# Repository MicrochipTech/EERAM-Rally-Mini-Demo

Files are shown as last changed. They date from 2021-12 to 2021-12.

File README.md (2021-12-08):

# EERAM Rally Mini Demo

https://user-images.githubusercontent.com/7294232/145284501-e43a5de2-cd9b-4e7f-be3a-1c69db363a6e.mp4

[Full Video](https://vimeo.com/604094518)

## ABOUT
The demo is supposed to showcase the special capabilities of this part in a game that simulates a “Black Box” recorder function. So that the race outcome can be examined after the fact any number of times. From the beginning of the race, every move by the driver, and the positions of the other cars is recorded 30 times a second into the EERAM which can hold 30 seconds of race time. If it becomes full, the program wraps back to the beginning to form a circular buffer, always marking the last sample taken.

The demo uses an SPI EERAM part, with a density of 64kbits, the  [**48L640**](https://www.microchip.com/wwwproducts/en/48L640). The EERAM is mounted onto a removable PIM board. By removing the board, it gives the customer the clear message that this memory can be disturbed or removed from power at any time, and still retain the data written to it up to that point. The EERAM family includes lower and higher density parts (upwards to 1Mbit), on I2C and SPI serial buses. Only the 64K SPI PIM and 1M Click boards are supported by this demo. By being removable, the PIM board allows for immediate communications and power disturbance, so that the data-saving features of the EERAM can be clearly demonstrated.

EERAM is a standalone SRAM memory with shadow EEPROM backup that retains the contents of the SRAM memory when system power is lost. The EERAM uses a small external capacitor (VCAP on the PIM
board) to provide the energy needed to store the contents of the SRAM onto the EEPROM whenever power is lost. Unlike NVSRAM, no external battery is needed. EERAM offers unlimited erase and write cycles to the SRAM memory and FRAM-like functionality at a fraction of the price.

## Mini Rally Game Board
The board showcases some other Microchip components. This includes the PIC18F47K40 8-bit MCU, and the MCP16252 DC/DC Boost converter. Power is supplied by two AAA batteries which are reverse
polarity protected. Power is controlled by a small slide switch on the back near the batteries. The boost converter ensures that every ounce of juice from the batteries will be available to the game.

Besides the supplied EERAM PIM board socket on the side, there is also a MikroBUS™ (Click board) interface to the back, where the 1Mbit EERAM Click demo board (in production soon) can be plugged in and used instead of the PIM. Future software versions may also support I2C PIM boards, and be able to use the larger memory array, but at this point, using the Click board can only record 64K of data, same as the PIM. The demo will only be supplied with the PIM.

The display used is a 128 x 160 pixel TFT display with LED backlight. The game operation is smooth and clear, taking advantage of the processing power of this 8-bit MCU and of the display resolution and color capabilities. Dimming is controlled by an MCU PWM channel.

Sound is produced by a rear-facing Piezo speaker. We have tried to avoid annoying continuous sounds, but some basic sounds have been added to enhance the demo board experience, such as a sound when the racer hits another car, when the PIM is unplugged or plugged in, and when the race review (instant-replay) mode is selected. Presently, there is no option to disable sound.

## Using the Demo
Power is controlled by a slide switch near the batteries (circled below). Always turn the switch to “0” when not in use to save battery life.

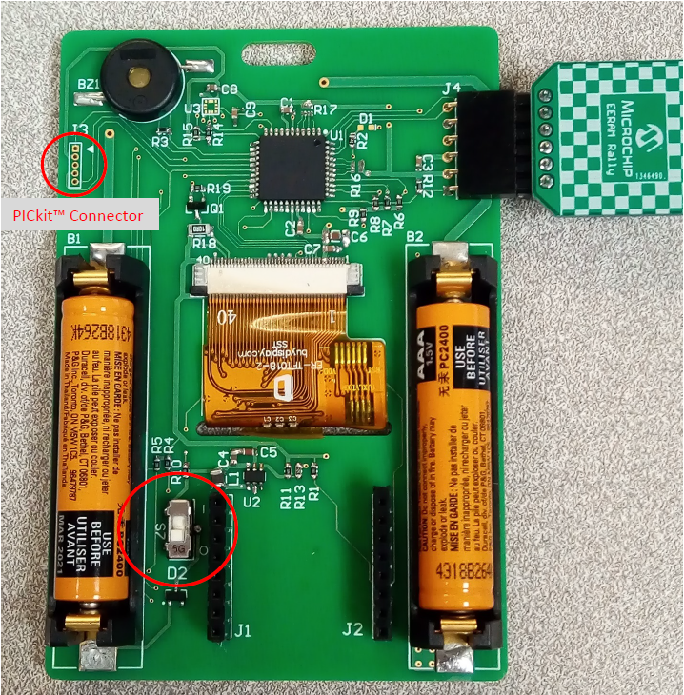
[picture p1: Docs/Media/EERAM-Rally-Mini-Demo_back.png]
Demonstration


On Power ON, the screen will splash the Microchip name and logo then instruct the user to hit either the “A” button, to begin a new race, or the “B” button, to review the last race. The EERAM PIM must be plugged in correctly for either of these modes to operate.

The directional buttons are used to steer the red car around the competitor cars. The user can move forward and back, but most of the time just left and right buttons are the best to use.

Just like the red wedge demo, users can continue racing until a crash (the object is not to win but rather to avoid a crash), or until power is turned off or the memory card is unplugged. Afterwards, the user can either begin a new race or review the previous one. After reviewing it once, it pauses and repeats forever, or until a new race is selected. The competitor car pattern is hard coded, so every race offers the same challenge. If you don’t crash while racing, the track pattern will repeat itself after about a minute, but there are some tight spots which are hard to complete without practice.

Demonstration

## **Support**
To submit a support ticket request, please contact [Microchip Support](https://microchipsupport.force.com/s/)

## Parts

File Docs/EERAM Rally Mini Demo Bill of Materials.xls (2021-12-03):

Quantity | Designator | Description_ | Manufacturer 1 | Manufacturer Part Number 1 | Supplier 1 | Supplier Part Number 1 | Supplier 100pc Unit Price | Extended
2 | B1, B2 | BATT HOLDER 1CELL SMD AAA | Keystone Electronics | 1020 | Digi-Key | 36-1020-ND | 1.91 | 3.82
1 | BZ1 | MECH HW Buzzer Single Tone 4kHz Piezo 30V SMD | TDK Corporation | PS1240P02CT3 | Digi-Key | 445-5229-1-ND | 0.5256 | 0.5256
6 | C1, C2, C3, C7, C8, C9 | CAP CER 0.1uF 50V 20% X7R SMD 0603 | TDK, KEMET, Panasonic | C1608X7R1H104M, | local stock |  |  | 0
1 | C4 | CAP CER 4.7uF 10V 10% X5R SMD 0603, | TDK, KEMET, Panasonic | C0603C475K8PACTU | local stock | 445-5098-1-ND, 399-5503-1-ND, PCC2479CT-ND |  | 0
1 | C5 | CAP CER 10uF 10V 20% X5R SMD 0603 | TDK, KEMET, Panasonic | ECJ-1VB1A106M | local stock |  |  | 0
1 | C6 | CAP CER 10uF 16V 10% X7R SMD 1206 (10V 0603 can be substituted with care in soldering) | TDK | C3216X7R1C106K | local stock | 445-4042-1-ND | 0.1146 | 0.1146
0 | D1, do not populate | DIO LED RED 2V 30mA 2mcd Clear SMD 0603 | Lite-On | LTST-C190EKT | Digi-Key | 160-1182-1-ND | 0.0954 | 0
1 | D2 | DIO Schottky SOT23-3 | ON Semi, others | BAT54 or BAT17 | Digi-Key | BAT54FSCT-ND | 0.081 | 0.081
2 | J1, J2 | Header, female, TH, Vert, 0.1", 8-pos, trim leads to flush with board before solder | Samtec |  | local stock |  |  | 0
0 | J3, do not populate | For debugger pins, keep holes clear | none | none | none | None |  | 0
1 | J4 | Header, female, TH, Right-Angle. 0.1", 6-pos | Sullins | PPPC061LGBN-RC | Digi-Key | S5481-ND | 0.5029 | 0.5029
1 | L1 | IND 4.7UH 920MA 260 MOHM, or similar. An alternate is provided in proto run | Taiyo Yuden | CBC2518T4R7M | Digikey | 587-1621-1-ND | 0.1035 | 0.1035
1 | LCD1 | DISPLAY LCD TFT 128x160 GRAPHIC ILI9163C ER-TFT018-2 | EastRising Technology Co., Limited | ER-TFT018-2 | BUYDISPLAY.COM | ER-TFT018-2 | 3.51 | 3.51
1 | Q1 | TRANS FET N-CH BSS138 | ON Semi, others | BSS138 | local stock | BSS138CT-ND | 0.0902 | 0.0902
11 | R1, R4, R5, R6, R7, R8, R9, R12, R14, R15, R19 | RES TKF 10k 1% 1/10W SMD 0603 | Panasonic, Vishay Dale | ERJ-3EKF1002V | local stock | P10.0KHCT-ND |  | 0
0 | R2, do not populate | RES TKF 330R 1% 1/10W SMD 0603 | Panasonic, Vishay Dale | ERJ-3EKF3300V | local stock | P330HCT-ND |  | 0
2 | R3, R10 | RES TKF 1k 1% 1/10W SMD 0603 | Panasonic, Vishay Dale | ERJ-3EKF1001V | local stock | P1.00KHCT-ND, |  | 0
1 | R11 | RES TKF 1.69M 1% 1/10W SMD 0603 | Panasonic, Vishay Dale | CRCW06031M69FKEA, | Digi-Key | 541-1.69MHCT-ND | 0.0139 | 0.0139
1 | R13 | RES TKF 1M 1% 1/10W SMD 0603 | Panasonic, Vishay Dale | ERJ-3EKF1004V | local stock | P1.00MHCT-ND |  | 0
0 | R16, R17, do not populate | RES NET TKF 10k 5% 31mW SMD 0402x4 | Panasonic Electronic Components | EXB-N8V103JX | local stock | Y10103TR-ND or Y10103CT-ND | 0.0363 | 0
1 | R18 | RES TKF 10R 1% 1/4W SMD 1206 | Panasonic Electronic Components | ERJ-8ENF10R0V | local stock | P10.0FCT-ND |  | 0
6 | S1, S2, S3, S4, S5, S6 | SWITCH TACT SPST 12V 50mA PTS645SM43SMTR92 LFS SMD | C&K Components | PTS645SM43SMTR92 LFS | Digi-Key | CKN9112CT-ND | 0.2641 | 1.5846
1 | S7 | SWITCH SLIDE SPDT 12V 200MA CL-SB-12B-01T SMD | Copal Electronics Inc. | CL-SB-12B-01T | Digi-Key | 563-1318-1-ND | 0.7296 | 0.7296
1 | U1 | MCHP MCU 8-BIT 64MHZ 64kB 1kB PIC18F47K40-I/PT | Microchip Production | MIC6680 | Microchip Production | MIC6680 |  | 0
1 | U2 | IC REG BST ADJ 0.1A SYNC SOT23-6 MCP16252T-I/CH | Microchip Technology Inc | MCP16252T-I/CH | Microchip Production | MCP16252T-I/CH-ND |  | 0
0 | U3, do not populate | SENSOR ACCEL BMA250E SMD LGA-12 - now discontinued, seeking replacement | Bosch Sensortec | BMA250E | Digi-Key | Discontinued, do not populate |  | 0
 |  |  |  |  |  |  |  | 11.0759

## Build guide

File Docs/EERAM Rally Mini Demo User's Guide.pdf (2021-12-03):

# MPD EERAM Rally Mini Demo – USER

# GUIDE

Version 1.0

Thank you for using and showcasing this demo to our current and potential customers. The Memory Products Division appreciates your time and dedication towards expanding the portfolio of Microchip products that our customers use. This is a sales tool we will try to get into the hands of every Microchip field sales and engineers, but not intended as a board to be distributed to customers, and it not planned on being put on sale. There will likely not be enough produced to replace units that are lost, broken or given away.

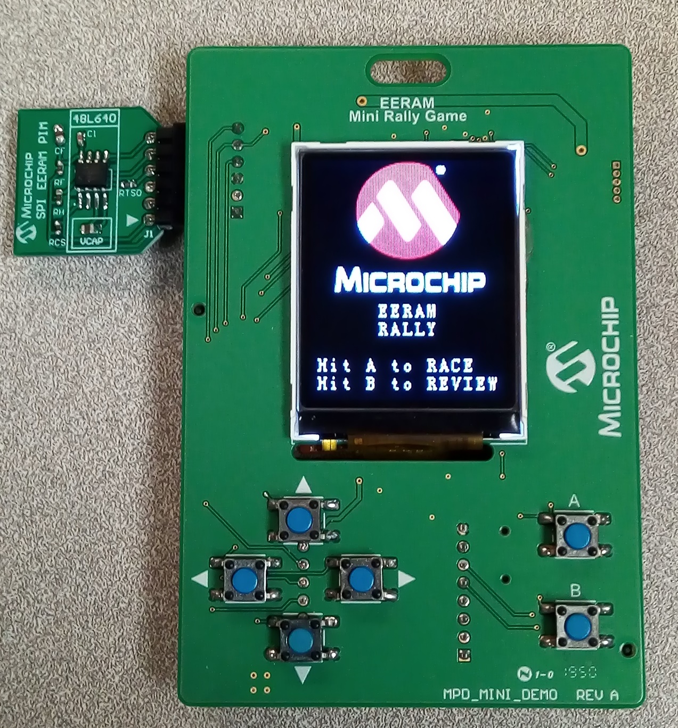
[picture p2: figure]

# About

This demo is based on the large red wedge demo that has been used at MASTERs and sent to trade shows around the world. This miniature version follows the same basic operating steps, but in a handheld format that allows for many copies to be made and distributed to field sales and apps.

The demo uses an SPI EERAM part, with a density of 64kbits, the 48L640. The EERAM is mounted onto a removable PIM board. By removing the board, it gives the customer the clear message that this memory can be disturbed or removed from power at any time, and still retain the data written to it up to that point.

The EERAM family includes lower and higher density parts (upwards to 1Mbit), on I2C and SPI serial buses. Only the 64K SPI PIM and 1M Click boards are supported by this demo. By being removable, the PIM board allows for immediate communications and power disturbance, so that the data-saving features of the EERAM can be clearly demonstrated.

EERAM is a standalone SRAM memory with shadow EEPROM backup that retains the contents of the SRAM memory when system power is lost. The EERAM uses a small external capacitor (VCAP on the PIM board) to provide the energy needed to store the contents of the SRAM onto the EEPROM whenever power is lost. Unlike NVSRAM, no external battery is needed. EERAM offers unlimited erase and write cycles to the SRAM memory and FRAM-like functionality at a fraction of the price.

The demo is supposed to showcase the special capabilities of this part in a game that simulates a “Black Box” recorder function. So that the race outcome can be examined after the fact any number of times. From the beginning of the race, every move by the driver, and the positions of the other cars is recorded 30 times a second into the EERAM which can hold 30 seconds of race time. If it becomes full, the program wraps back to the beginning to form a circular buffer, always marking the last sample taken.

# The Mini Rally Game board

The board showcases some other Microchip components. This includes the PIC18F47K40 8-bit MCU, and the MCP16252 DC/DC Boost converter. Power is supplied by two AAA batteries which are reverse polarity protected. Power is controlled by a small slide switch on the back near the batteries. The boost converter ensures that every ounce of juice from the batteries will be available to the game.

Besides the supplied EERAM PIM board socket on the side, there is also a MikroBUS™ (Click board) interface to the back, where the 1Mbit EERAM Click demo board (in production soon) can be plugged in and used instead of the PIM. Future software versions may also support I2C PIM boards, and be able to use the larger memory array, but at this point, using the Click board can only record 64K of data, same as the PIM. The demo will only be supplied with the PIM.

The display used is a 128 x 160 pixel TFT display with LED backlight. The game operation is smooth and clear, taking advantage of the processing power of this 8-bit MCU and of the display resolution and color capabilities. Dimming is controlled by an MCU PWM channel.

Sound is produced by a rear-facing Piezo speaker. We have tried to avoid annoying continuous sounds, but some basic sounds have been added to enhance the demo board experience, such as a sound when the racer hits another car, when the PIM is unplugged or plugged in, and when the race review (instantreplay) mode is selected. Presently, there is no option to disable sound.

# Using the Demo

Power is controlled by a slide switch near the batteries (circled below). Always turn the switch to “0” when not in use to save battery life.

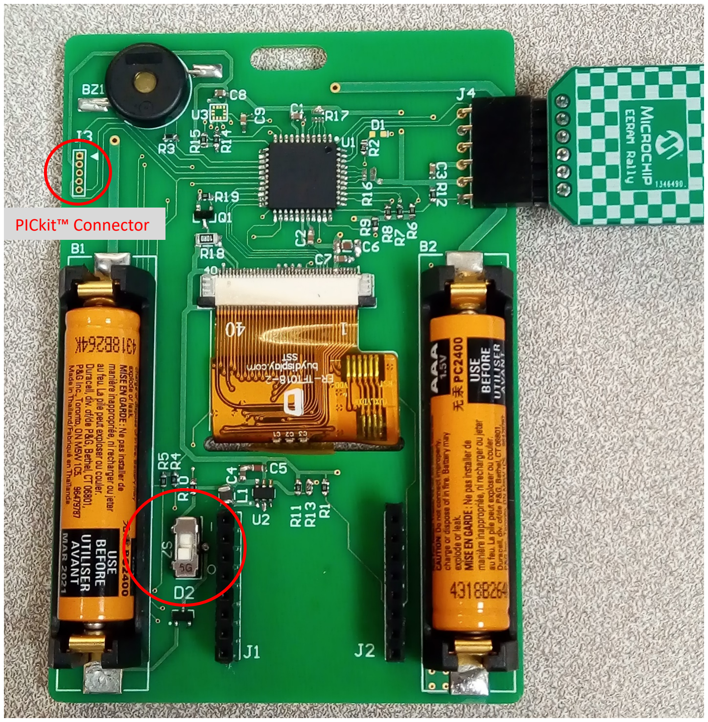
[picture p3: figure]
PICkit™ Connector

On Power ON, the screen will splash the Microchip name and logo then instruct the user to hit either the “A” button, to begin a new race, or the “B” button, to review the last race. The EERAM PIM must be plugged in correctly for either of these modes to operate.

The directional buttons are used to steer the red car around the competitor cars. The user can move forward and back, but most of the time just left and right buttons are the best to use.

Just like the red wedge demo, users can continue racing until a crash (the object is not to win but rather to avoid a crash), or until power is turned off or the memory card is unplugged. Afterwards, the user can either begin a new race or review the previous one. After reviewing it once, it pauses and repeats forever, or until a new race is selected. The competitor car pattern is hard coded, so every race offers the same challenge. If you don’t crash while racing, the track pattern will repeat itself after about a minute, but there are some tight spots which are hard to complete without practice.

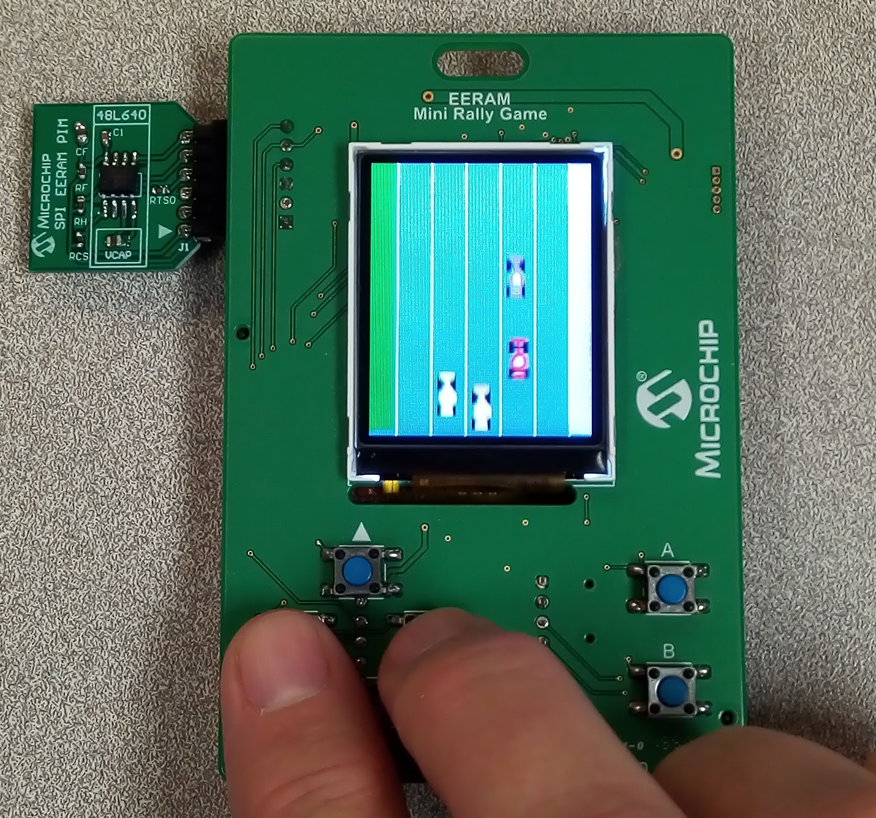
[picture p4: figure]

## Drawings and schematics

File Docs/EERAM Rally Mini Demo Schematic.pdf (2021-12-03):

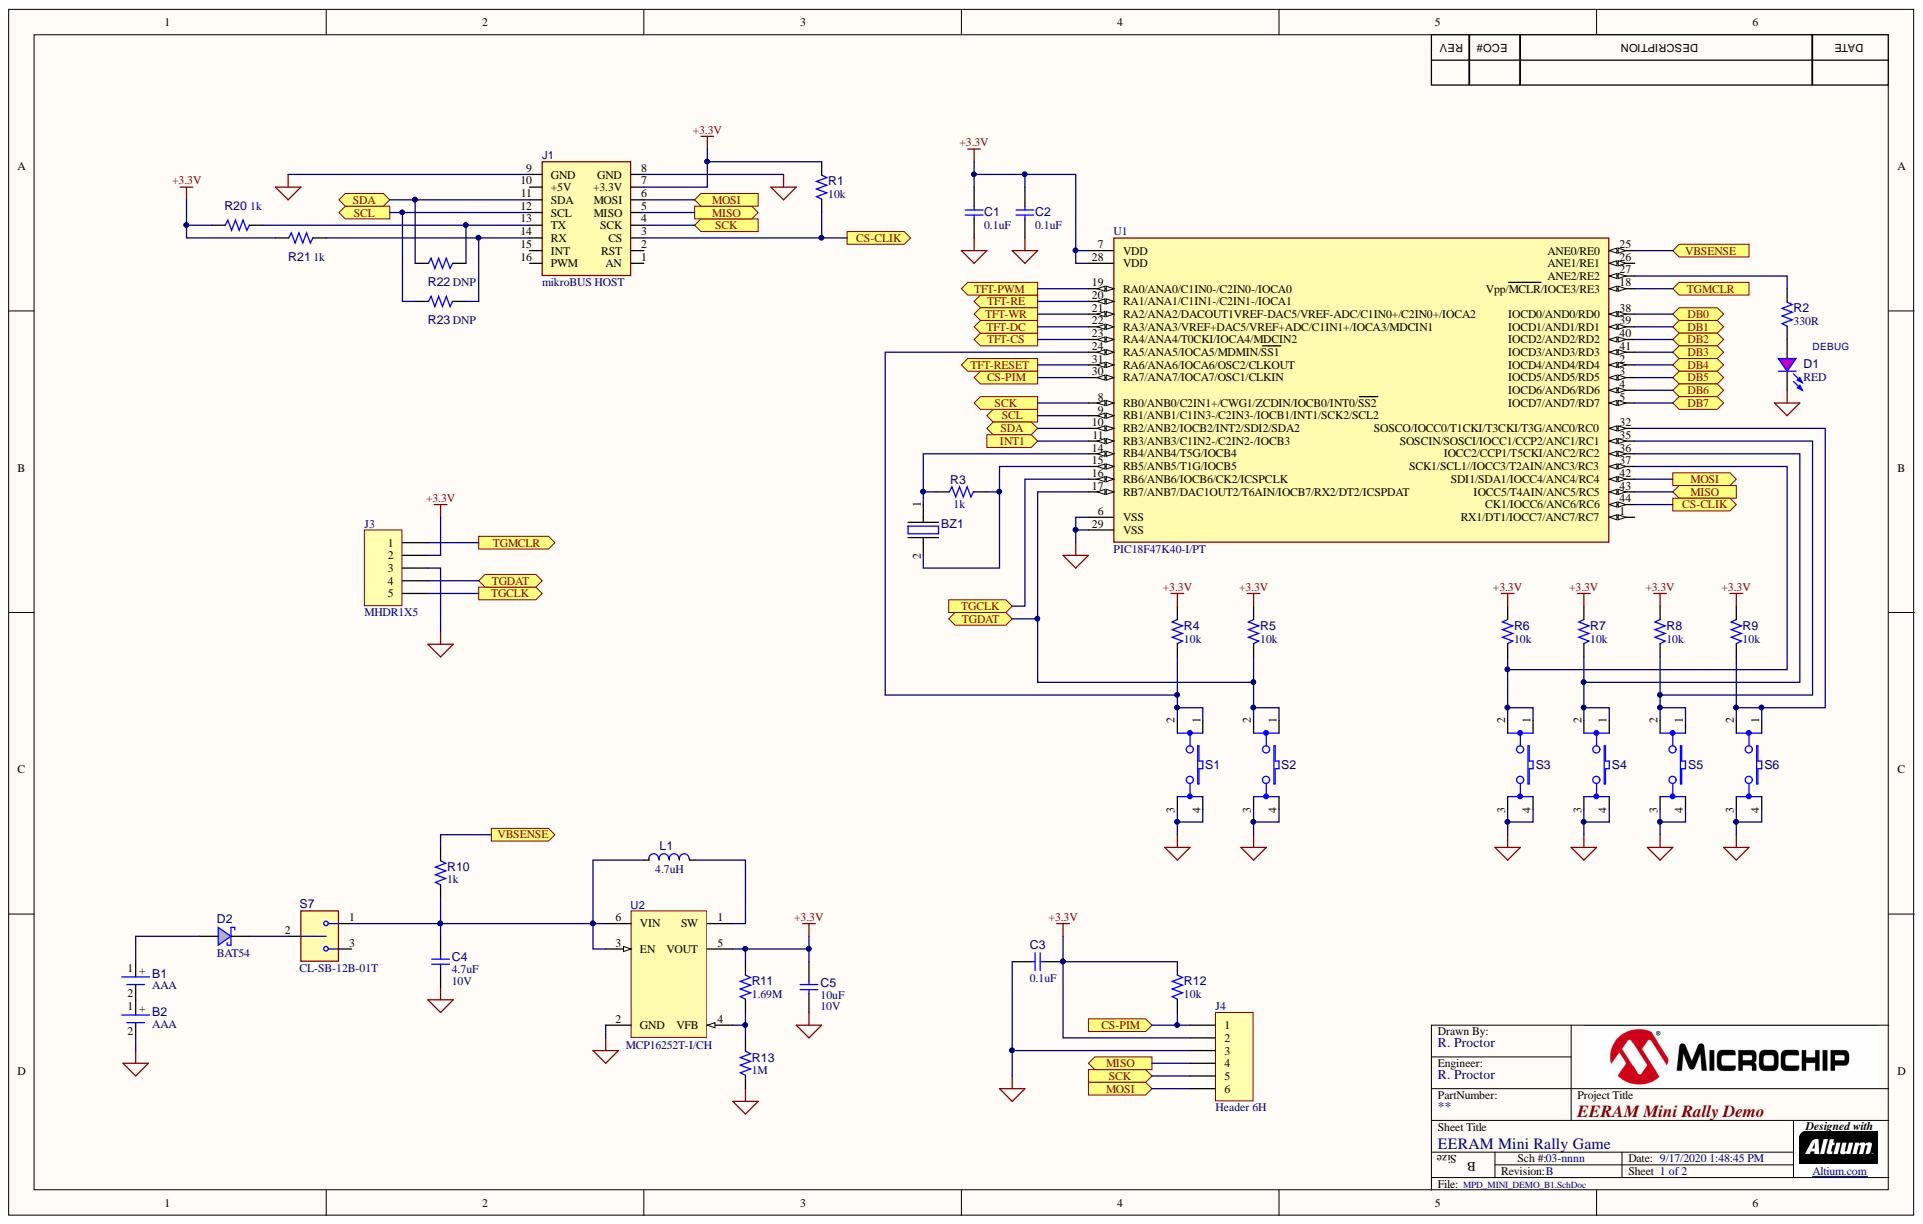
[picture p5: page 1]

RB5/ANB5/T1G/IOCB5 15

RB7/ANB7/DAC1OUT2/T6AIN/IOCB7/RX2/DT2/ICSPDAT 17

VSS 29

PartNumber: ** | Project Title EERAM Mini Rally Demo

Sheet Title EERAM Mini Rally Game | Designed with Altium.com

Sch #: 03-nnnn | Date: 9/17/2020 1:48:45 PM
Revision: B | Sheet 1 of 2

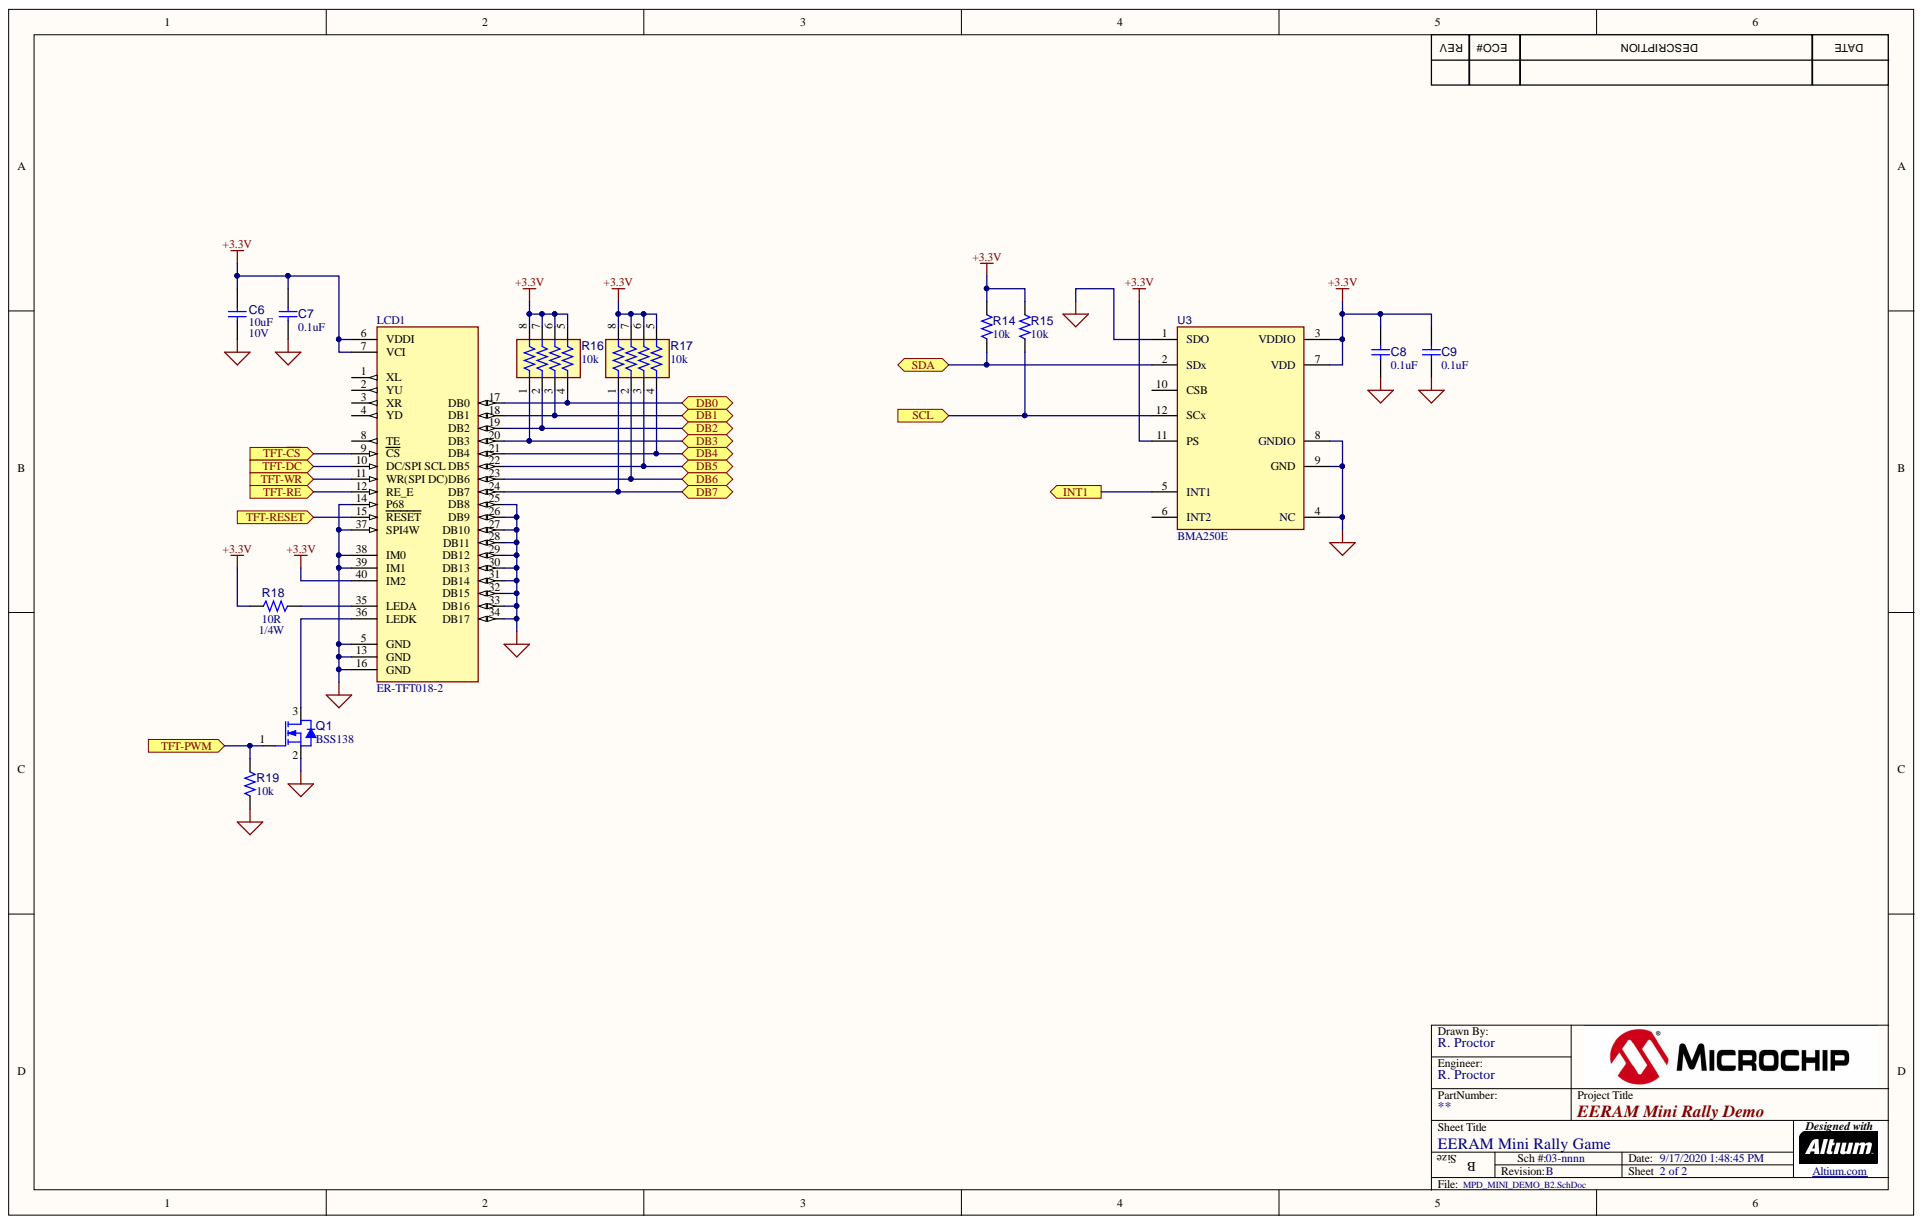
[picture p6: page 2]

Par tNumber : * * | Project T i tl e E E R AM Mini R ally Dem o

Sheet T i tl e E ERAM Mi n i Ral l y Game | Des igned w ith A l tium.com

Sch #: 03-nnnn B | Date: 9/17/2020 1:48:45 PM
Revi s ion: | Sheet 2 of 2

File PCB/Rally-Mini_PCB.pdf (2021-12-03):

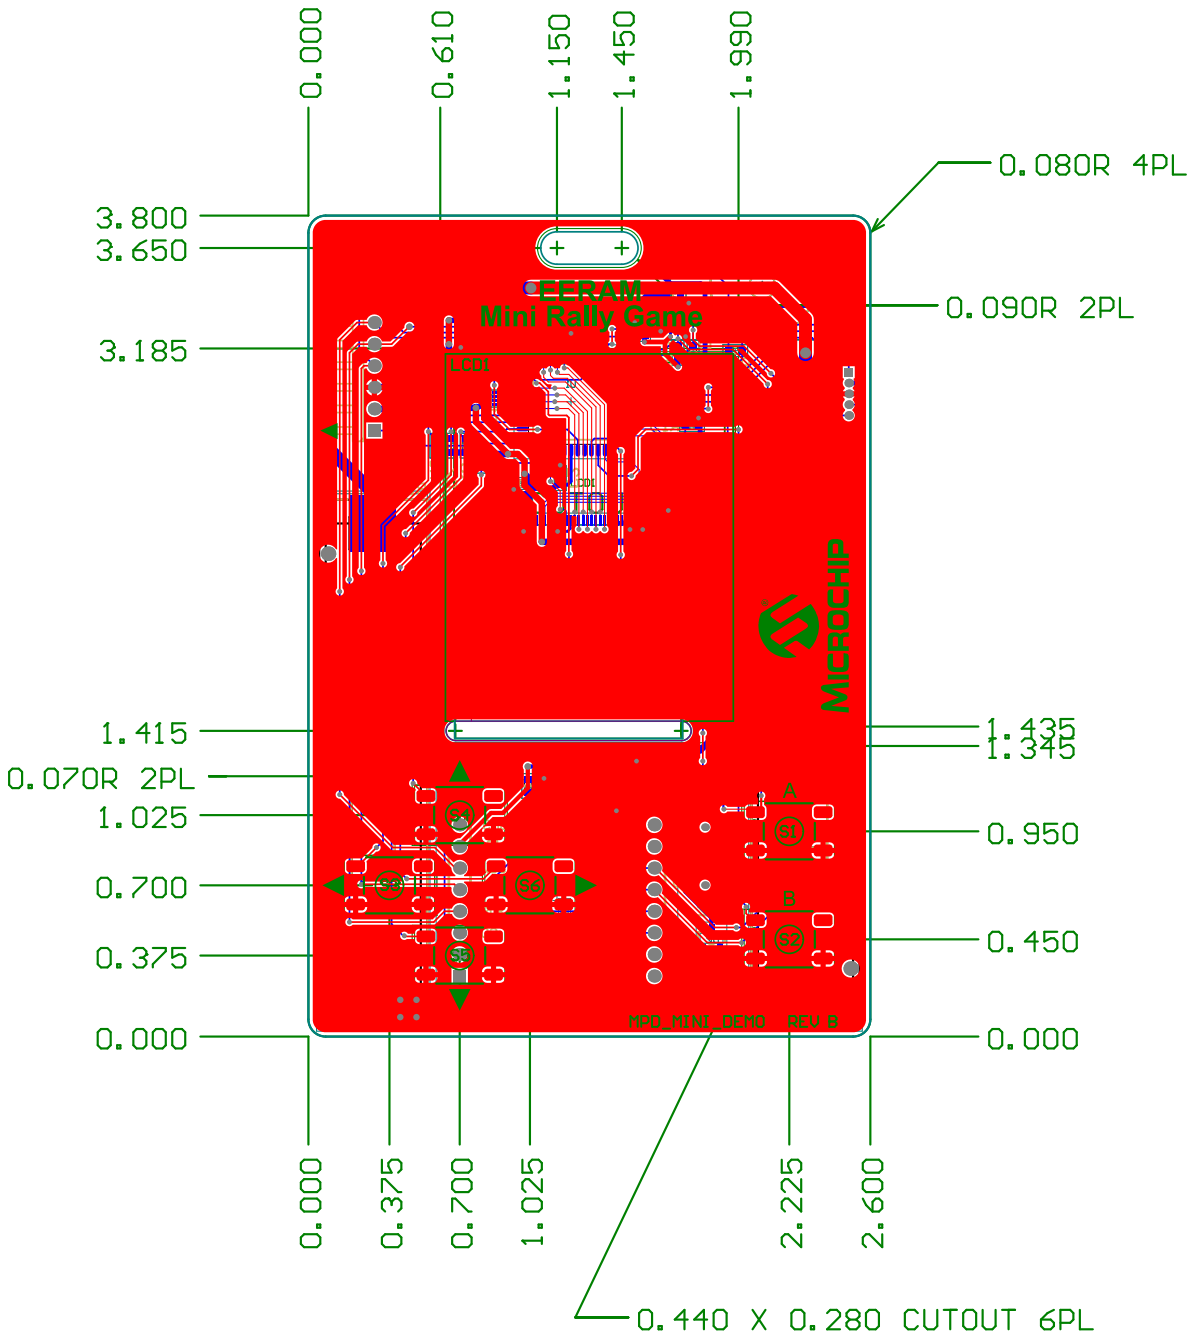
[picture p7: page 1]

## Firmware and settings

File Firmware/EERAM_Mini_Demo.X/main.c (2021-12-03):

/**
  Generated Main Source File

  Company:
    Microchip Technology Inc.

  File Name:
    main.c

  Summary:
    This is the main file generated using MPLAB(c) Code Configurator

  Description:
    This header file provides implementations for driver APIs for all modules selected in the GUI.
    Generation Information :
        Product Revision  :  MPLAB(c) Code Configurator - 3.25
        Device            :  PIC18F47K40
        Driver Version    :  2.00
    The generated drivers are tested against the following:
        Compiler          :  XC8 1.38
        MPLAB             :  MPLAB X 3.45
 */

/*
    (c) 2016 Microchip Technology Inc. and its subsidiaries. You may use this
    software and any derivatives exclusively with Microchip products.

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
    IN NO EVENT WILL MICROCHIP BE LIABLE FOR ANY INDIRECT, SPECIAL, PUNITIVE,
    INCIDENTAL OR CONSEQUENTIAL LOSS, DAMAGE, COST OR EXPENSE OF ANY KIND
    WHATSOEVER RELATED TO THE SOFTWARE, HOWEVER CAUSED, EVEN IF MICROCHIP HAS
    BEEN ADVISED OF THE POSSIBILITY OR THE DAMAGES ARE FORESEEABLE. TO THE
    FULLEST EXTENT ALLOWED BY LAW, MICROCHIP'S TOTAL LIABILITY ON ALL CLAIMS IN
    ANY WAY RELATED TO THIS SOFTWARE WILL NOT EXCEED THE AMOUNT OF FEES, IF ANY,
    THAT YOU HAVE PAID DIRECTLY TO MICROCHIP FOR THIS SOFTWARE.

    MICROCHIP PROVIDES THIS SOFTWARE CONDITIONALLY UPON YOUR ACCEPTANCE OF THESE
    TERMS.
 * 
 * As of January 14, 2020, this version now applies only to the new Demo Board PCB
 * MCC generated files to support SPI1 and I2C2 master modes were added
 */
#include <xc.h>
#include <stdint.h>
#include "mcc.h"
#include "litegui.h"
#include "hardware.h"
#include "fonts.h"
#include "images.h"
#include "backlight.h"
#include "audio.h"
#include "controls.h"
#include "spi1.h"
//#include "i2c2_driver.h"
//#include "EERAM_driver.h"
#include <math.h>
#include "indiana.h"

// *** DEFINES ****************************************************************
//  Lane positions are along the X axis, left to right

#define LANE1  15
#define LANE2  35
#define LANE3  55
#define LANE4  75
#define LANE5  95
#define LANE6  115
// The car positions are shifted over a bit to center them in the lane lines
#define CAR_AX  17
#define CAR_BX  37
#define CAR_CX  57
#define CAR_DX  77
#define CAR_EX  97

// *** Function Prototypes ****************************************************
void runDisplay(uint8_t buttons);
void state_initial(uint8_t buttons);
void state_initial_hold(uint8_t buttons);
void state_track_draw(uint8_t buttons);
void state_track_run(uint8_t buttons);
void state_replay(uint8_t buttons);
void state_screensaver_start(uint8_t buttons);
void state_screensaver_hold(uint8_t buttons);
void state_screensaver_exit(uint8_t buttons);
void lane(uint8_t xl);
uint8_t collision(void);

void fix_borders(void);
void maneuvere(void);
void initialize_record(void);

void PIM_record(uint16_t address);
void PIM_playback(uint16_t address);
void PIM_Set_Status(void);
uint8_t PIM_error(void);
void PIM_store(void);
void MESSAGE_NewGame(void);
void MESSAGE_Removed(void);
void MESSAGE_Restored(void);
void MESSAGE_Rewind(void);
uint16_t EERAM_FindEnd(void);
void BEEP_low(void);
void BEEP_high(void);
void BEEP_crash(void);
void BEEP_scream(void);
void BEEP_rewind(void);
void BEEP_indiana(void);
void BEEP_note(uint16_t note, uint16_t duration);


// *** Enums ******************************************************************

enum {
    DS_INITIAL,
    DS_INITIAL_HOLD,
    DS_TRACK_DRAW,
    DS_TRACK_RUN,
    DS_CRASH,
    DS_REPLAY,
    DS_ERROR,
    DS_REMOVED,
    DS_REPLACED,
    DS_SCREENSAVER_START,
    DS_SCREENSAVER_HOLD,
    DS_SCREENSAVER_EXIT

} DISPLAY_STATES;

enum {
    COMP_NONE,
    COMP_INITIAL,
    COMP_MOVE
} COMPETITOR_STATES;

// *** Global Variables *******************************************************
uint8_t TickMs = 0;
CONSOLE MainConsole;
//SPIPACKET gestDataIn, gestDataOut;
uint8_t dState = DS_INITIAL, x, y, mx, my;
uint8_t ax, bx, cx, dx, ex;
uint16_t ay, by, cy, dy, ey;

uint8_t i2cbuff[] = {0, 1, 2, 3, 4, 5, 6, 7};
uint8_t overflow = 0xFF;

//extern const unsigned char gauntlet[];

/*const unsigned char gauntlet[64] = {
    0x0, 0xA, 0x14, 0x0, 0x0, 0x0, 0x10, 0x9, 0x0, 0x0, 0x10, 0x3, 0x8, 0x0, 0x0, 0x0, 0x8, 0x0, 0x16, 0x1, 0x0, 0x8, 0x0, 0x0,
    0x13, 0x8, 0x4, 0x0, 0x0, 0x9, 0x0, 0x14, 0x0, 0x2, 0x9, 0x0, 0x0, 0x0, 0x0, 0x0, 0xE, 0x0, 0x0, 0x0, 0xE, 0x10, 0x0, 0x0,
    0x0, 0x0, 0x14, 0x8, 0x0, 0x2, 0x11, 0x0, 0x0, 0x0, 0x2, 0x1C, 0x0, 0x0, 0x0, 0x00

};*/

const unsigned char gauntlet[64] = {
    0x0, 0x1D, 0x2, 0x0, 0x0, 0x0, 0x1D, 0x2, 0x0, 0xC, 0x13, 0x0, 0xC, 0x2, 0x0, 0x0, 0xE, 0x0, 0x0, 0x5, 0x0, 0x12, 0x1, 0x8,
    0x0, 0x14, 0x0, 0x0, 0x0, 0x1C, 0x0, 0x0, 0x8, 0x0, 0x2, 0x0, 0x1, 0x16, 0x8, 0x1, 0x0, 0x0, 0x1D, 0x0, 0x0, 0x13, 0x4, 0x0,
    0x3, 0x10, 0x4, 0xA, 0x0, 0x05, 0x2, 0x0, 0xC, 0x0, 0x3, 0x0, 0x0, 0x10, 0x9, 0x0

};

#define record_length  2046

//unsigned char capture[512][4];

uint16_t fineCount = 0, courseCount = 0;

uint16_t dTimer = 0, record_begin = 0;

uint8_t competitorStateA = COMP_NONE;
uint8_t competitorStateB = COMP_NONE;
uint8_t competitorStateC = COMP_NONE;
uint8_t competitorStateD = COMP_NONE;
uint8_t competitorStateE = COMP_NONE;
// ****************************************************************************


// *** Main *******************************************************************

void main(void) {
    uint8_t testButtons = 1;

    // Workaround for NVMREG bit bug in silicon    
#ifdef _PIC18_H
    NVMCON1bits.NVMREG = 0b10;
#endif

    SYSTEM_Initialize();
    //I2C2_Initialize();
    SPI1_Initialize();

    audio_init();
    //audio_set_tune(&MyIndiana);


    // Turn off boost regulator as not to cause audio noise in the speaker.
    // USB should be checked first(USBDETECT)to see if it is plugged in.
    // If USB is not plugged in, then set USBDETECT as output and set high
    TRISEbits.TRISE1 = 0;
    LATEbits.LATE1 = 1;

    backlightInit();
    lg_init();

    INTCON = 0b11000000; // Enable Global and Peripheral - no priority

    cls(BLACK);
    console_new(&MainConsole, 5, 95, 16, 6, WHITE, GRAY010, &font8x12);

    while (1) {
        if (TickMs > 13) {
            TickMs = 0;
            testButtons = checkButtons();
            runDisplay(testButtons);
        }
    }
}

void runDisplay(uint8_t buttons) {
    switch (dState) {
        default:
            dState = DS_INITIAL;
            break;

        case DS_INITIAL: // Initial start up screen
            state_initial(buttons);
            break;

        case DS_INITIAL_HOLD:
            //initialize_record();
            state_initial_hold(buttons);
            break;

        case DS_TRACK_DRAW: // Draw the current zone
            dTimer = 0;
            record_begin = 0x00;
            overflow = 0x00;
            MESSAGE_NewGame();
            delay_ms(200);
            state_track_draw(buttons);
            dState = DS_TRACK_RUN;
            break;

        case DS_TRACK_RUN: // Update the current zone
            if (buttons & KEY_B) {
                state_track_draw(buttons);
                dState = DS_REPLAY;
                EERAM_FindEnd();
                dTimer = record_begin;
            } else state_track_run(buttons);
            break;

        case DS_CRASH:

            if (buttons & KEY_B) {

                state_track_draw(buttons);
                if (overflow == 0xFF) record_begin = 0x00;
                else EERAM_FindEnd(); //this sets the record_begin
                dTimer = record_begin;
                MESSAGE_Rewind();
                BEEP_rewind();
                //delay_ms(100);
                state_track_draw(buttons);
                dState = DS_REPLAY;

            } else if (buttons & KEY_A) {
                //state_track_draw(buttons);
                dState = DS_INITIAL_HOLD;
            }
            break;

        case DS_ERROR:
            MESSAGE_Removed(); //show message 
            BEEP_low();
            dState = DS_REMOVED;
            break;

        case DS_REMOVED:
            if (PIM_error()) {
                dState = DS_REMOVED;
            } else {

                BEEP_high();
                MESSAGE_Restored(); //show message 
                dState = DS_REPLACED;

                EERAM_FindEnd();
                dTimer = record_begin;
            }
            break;
        case DS_REPLACED:
            if (PIM_error()) {
                MESSAGE_Removed(); //show message 
                BEEP_low();
                dState = DS_REMOVED;
            } else {
                if (buttons & KEY_B) {
                    MESSAGE_Rewind();
                BEEP_rewind();
                    state_track_draw(buttons);
                    EERAM_FindEnd();
                    dTimer = record_begin;

                    //dTimer = record_begin;

                    dState = DS_REPLAY;
                    //SPI1_Open();
                    //while(buttons & KEY_B);
                    delay_ms(100);

                } else if (buttons & KEY_A) {
                    //state_track_draw(buttons);
                    //BEEP_high();
                    dState = DS_INITIAL_HOLD;
                }
            }
            break;
        case DS_REPLAY: // Update the current zone

            if (buttons & KEY_A) {
                //state_track_draw(buttons);
                dState = DS_INITIAL_HOLD;
            } else state_replay(buttons);
            break;

        case DS_SCREENSAVER_START: // Transition to screen saver
            state_screensaver_start(buttons);
            break;

        case DS_SCREENSAVER_HOLD: // Screen Saver Mode
            state_screensaver_hold(buttons);
            break;

        case DS_SCREENSAVER_EXIT: // Exit screen saver
            state_screensaver_exit(buttons);
            break;
    }
}

void state_initial(uint8_t buttons) {
    image(29, 1, &mchp_meatball);
    image(15, 70, &microchip);
    console_show(&MainConsole);

    console_puts(&MainConsole, "     EERAM     ");
    console_puts(&MainConsole, "     RALLY     ");
    console_puts(&MainConsole, " ");
    backlightFadeUp();
    //delay_ms(100);

    console_puts(&MainConsole, "Hit A to RACE  ");
    //SPI1_Open();
    //initialize_record();
    //delay_ms(100);
    //delay_ms(100);
    //delay_ms(100);
    delay_ms(100);
    delay_ms(100);
    delay_ms(100);
    delay_ms(100);
    console_puts(&MainConsole, "Hit B to REVIEW");
    //BEEP_indiana();
    //audio_play_tune();

    dState = DS_INITIAL_HOLD;
}

void state_initial_hold(uint8_t buttons) {
    //if (PIM_error() == 0) {
        if ((buttons & KEY_A)||(buttons & KEY_UP)) {
            audio_stop_tune();
            MESSAGE_NewGame();
            delay_ms(200);
            backlightFadeDown();
            initialize_record();
            cls(BLACK);
            dState = DS_TRACK_DRAW;
            fineCount = 0;
            courseCount = 0;
            dTimer = 0;
            record_begin = 0;
        } else if ((buttons & KEY_B)||(buttons & KEY_DOWN)){
            audio_stop_tune();
            EERAM_FindEnd(); //this sets the record_begin
            MESSAGE_Rewind();
            BEEP_rewind();
            //fineCount = 0;
            //courseCount = 0;
            dTimer = record_begin;
            delay_ms(100);
            dState = DS_REPLAY;
            state_track_draw(buttons);

        }
    //}
}

void state_track_draw(uint8_t buttons) {
    cls(GRAY128);
    backlightFadeUp();
    //dState = DS_TRACK_RUN;
    x = CAR_AX;
    y = 102;

    ax = CAR_AX;
    bx = CAR_BX;
    cx = CAR_CX;
    dx = CAR_DX;
    ex = CAR_EX;

    ay = 0;
    by = 0;
    cy = 0;
    dy = 0;
    ey = 0;

    competitorStateA = COMP_NONE;
    competitorStateB = COMP_NONE;
    competitorStateC = COMP_NONE;
    competitorStateD = COMP_NONE;
    competitorStateE = COMP_NONE;

    dTimer = record_begin;

    //Set the track lanes and sides
    setcolor(GREEN);
    rectangle(0, 130, LANE1, 29);
    rectangle(0, 0, LANE1, 140); //Drawing a solid green box always seems to be incomplete, so splitting it up to two operations
    //rectangle(0, 135, LANE1, 25);

    setcolor(GRAY204);
    rectangle(LANE6, 0, 119, 159);

    lane(LANE1);
    lane(LANE2);
    lane(LANE3);
    lane(LANE4);
    lane(LANE5);
    lane(LANE6);

}

void lane(uint8_t xl) {
    uint8_t y1;
    setcolor(WHITE);

    for (y1 = 0; y1 < 160; y1++) {
        plot(xl, y1);
    }
}

uint8_t collisionA() {
    uint8_t ty;

    ty = ay;

    if (dState != DS_TRACK_RUN) return 0;
    if (competitorStateA != COMP_MOVE) return 0;
    if ((x > (CAR_AX + 10)) || ((x + 10) < CAR_AX)) return 0;

    if (y >= ty) {
        if ((y - ty) < 24) return 1;
    } else if ((ty - y) < 24)return 1;

    return 0;
}

uint8_t collisionB() {
    uint8_t ty;

    ty = by;

    if (dState != DS_TRACK_RUN) return 0;
    if (competitorStateB != COMP_MOVE) return 0;
    if ((x > (CAR_BX + 10)) || ((x + 10) < CAR_BX)) return 0;

    if (y >= ty) {
        if ((y - ty) < 24) return 1;
    } else if ((ty - y) < 24)return 1;

    return 0;
}

uint8_t collisionC() {
    uint8_t ty;

    ty = cy;

    if (dState != DS_TRACK_RUN) return 0;
    if (competitorStateC != COMP_MOVE) return 0;
    if ((x > (CAR_CX + 10)) || ((x + 10) < CAR_CX)) return 0;

    if (y >= ty) {
        if ((y - ty) < 24) return 1;
    } else if ((ty - y) < 24)return 1;

    return 0;
}

uint8_t collisionD() {
    uint8_t ty;

    ty = dy;

    if (dState != DS_TRACK_RUN) return 0;
    if (competitorStateD != COMP_MOVE) return 0;
    if ((x > (CAR_DX + 10)) || ((x + 10) < CAR_DX)) return 0;

    if (y >= ty) {
        if ((y - ty) < 24) return 1;
    } else if ((ty - y) < 24)return 1;

    return 0;
}

uint8_t collisionE() {
    uint8_t ty;

    ty = ey;

    if (dState != DS_TRACK_RUN) return 0;
    if (competitorStateE != COMP_MOVE) return 0;
    if ((x > (CAR_EX + 10)) || ((x + 10) < CAR_EX)) return 0;

    if (y >= ty) {
        if ((y - ty) < 24) return 1;
    } else if ((ty - y) < 24)return 1;

    return 0;
}

void state_track_run(uint8_t buttons) {

    // Move the player as directed
    if (buttons & KEY_LEFT) {
        x--;
        if (x < 12) {
            x = 12;
        }
    }
    if (buttons & KEY_RIGHT) {
        x++;
        if (x > 102) {
            x = 102;
        }
    }

    if (buttons & KEY_UP) {
        y--;
        if (y < 2) y = 2;
    }

    if (buttons & KEY_DOWN) {
        y++;
        if (y > 132) y = 132;
    }
    fix_borders();
    maneuvere();

    PIM_record(dTimer * 4);
    //if(PIM_error) dState = DS_CRASH;

    if (collisionA() || collisionB() || collisionC() || collisionD() || collisionE()) {
        image(x, y, &car16); //redraw the car in case it is being covered
        delay_ms(100); //don't kill the game, just slow for a moment and move on
        dState = DS_CRASH;
        PIM_store();
        //BEEP_crash();
        BEEP_scream();

        //SPI1_Close();
    }
    fineCount++;
    if (fineCount > 48) {
        fineCount = 0;
        courseCount++;
        if (courseCount > 63) courseCount = 0;
    }

    dTimer++;

    if (dTimer > record_length) {
        dTimer = 0;
        overflow = 0xFE;
    }
}

void state_replay(uint8_t buttons) {

    PIM_playback(dTimer * 4); //read the record from the previously set address
    if (PIM_error()) dState = DS_ERROR;

    if ((x > 0xF0) || (x == 0x00)) //indicating end of record
    {
        //console_clear(&MainConsole);
        //console_puts(&MainConsole, "End of Playback");
        delay_ms(100);
        delay_ms(100);
        delay_ms(100);
        delay_ms(100);
        delay_ms(100);
        delay_ms(100);
        delay_ms(100);
        delay_ms(100);
        delay_ms(100);
        delay_ms(100);
        delay_ms(100);
        delay_ms(100);

        if (x == 0xFF)//specifically, if the record was less than full
        {
            record_begin = 0;

        } else {
            EERAM_FindEnd();
        }
        state_track_draw(buttons); //redraw the track
        dTimer = record_begin; //then reset pointer to beginning of record
        dState = DS_REPLAY;
        if (PIM_error()) dState = DS_ERROR;
        return;
    }

    fix_borders();
    maneuvere();
    dTimer++;
    if (dTimer > record_length) {
        dTimer = 0;
        // overflow = 0xFE;
    }
}

void initialize_record() {
    overflow = 0xFF;
    SPI1_Open();
    PIM_Set_Status(); //enable continuous writes and enable auto-store
    //if(PIM_error) dState = DS_CRASH;
    x = 0;
    y = 0;
    fineCount = 0;
    courseCount = 0;
    dTimer = 0;
    record_begin = 0;
    while (dTimer++ < record_length) PIM_record(dTimer * 4);
    if (PIM_error()) dState = DS_ERROR;
    dTimer = 0;
    //x = CAR_AX;
}

void maneuvere() {
    switch (competitorStateA) {
        default:
            break;

        case COMP_NONE:
            competitorStateA = COMP_NONE;
            break;

        case COMP_INITIAL:
            ax = CAR_AX;
            ay = 0;

            competitorStateA = COMP_MOVE;
            break;

        case COMP_MOVE:
            if (ay > 132) {
                setcolor(GRAY128);
                rectangle(ax, ay, 16, 27);
                competitorStateA = COMP_NONE;
            } else {
                ay++;
                image(ax, ay, &blu16);
                competitorStateA = COMP_MOVE;
            }

            break;
    }

    switch (competitorStateB) {
        default:
            break;

        case COMP_NONE:
            competitorStateB = COMP_NONE;
            break;

        case COMP_INITIAL:
            bx = CAR_BX;
            by = 0;

            competitorStateB = COMP_MOVE;
            break;

        case COMP_MOVE:
            if (by > 132) {
                setcolor(GRAY128);
                rectangle(bx, by, 16, 27);
                competitorStateB = COMP_NONE;
            } else {
                by++;
                image(bx, by, &yel16);
                competitorStateB = COMP_MOVE;
            }

            break;
    }

    switch (competitorStateC) {
        default:
            break;

        case COMP_NONE:
            competitorStateC = COMP_NONE;
            break;

        case COMP_INITIAL:
            cx = CAR_CX;
            cy = 0;
            competitorStateC = COMP_MOVE;
            break;

        case COMP_MOVE:
            if (cy > 132) {
                setcolor(GRAY128);
                rectangle(cx, cy, 16, 27);
                competitorStateC = COMP_NONE;
            } else {
                cy++;
                image(cx, cy, &org16);
                competitorStateC = COMP_MOVE;
            }

            break;
    }

    switch (competitorStateD) {
        default:
            break;

        case COMP_NONE:
            competitorStateD = COMP_NONE;
            break;

        case COMP_INITIAL:
            dx = CAR_DX;
            dy = 0;
            competitorStateD = COMP_MOVE;
            break;

        case COMP_MOVE:
            if (dy > 132) {
                setcolor(GRAY128);
                rectangle(dx, dy, 16, 27);
                competitorStateD = COMP_NONE;
            } else {
                dy++;
                image(dx, dy, &vio16);
                competitorStateD = COMP_MOVE;
            }

            break;
    }

    switch (competitorStateE) {
        default:
            break;

        case COMP_NONE:
            competitorStateE = COMP_NONE;
            break;

        case COMP_INITIAL:
            ex = CAR_EX;
            ey = 0;
            competitorStateE = COMP_MOVE;
            break;

        case COMP_MOVE:
            if (ey > 132) {
                setcolor(GRAY128);
                rectangle(ex, ey, 16, 27);
                competitorStateE = COMP_NONE;
            } else {
                ey++;
                image(ex, ey, &grn16);
                competitorStateE = COMP_MOVE;
            }

            break;
    }



    if (PIM_error()) dState = DS_ERROR;


    if (fineCount == 30) {
        if (gauntlet[courseCount] & 0x10) competitorStateA = COMP_INITIAL;
    }
    if (fineCount == 20) {
        if (gauntlet[courseCount] & 0x08) competitorStateB = COMP_INITIAL;
    }
    if (fineCount == 12) {
        if (gauntlet[courseCount] & 0x04) competitorStateC = COMP_INITIAL;
    }
    if (fineCount == 40) {
        if (gauntlet[courseCount] & 0x02) competitorStateD = COMP_INITIAL;
    }
    if (fineCount == 47) {
        if (gauntlet[courseCount] & 0x01) competitorStateE = COMP_INITIAL;
    }
}

void fix_borders() {
    if (x < (LANE1 + 2)) {
        setcolor(GREEN);
        rectangle(0, 0, LANE1, 159);
        lane(LANE1);
    }
    if ((x > (LANE2 - 17))&&(x < (LANE2 + 2))) lane(LANE2);
    if ((x > (LANE3 - 17))&&(x < (LANE3 + 2))) lane(LANE3);
    if ((x > (LANE4 - 17))&&(x < (LANE4 + 2))) lane(LANE4);
    if ((x > (LANE5 - 17))&&(x < (LANE5 + 2))) lane(LANE5);
    if ((x > (LANE6 - 17))&&(x < (LANE6 + 2))) {
        setcolor(GRAY204);
        rectangle(LANE6, 0, 119, 159);
        lane(LANE6);
    }
    image(x, y, &car16);
}

void state_screensaver_start(uint8_t buttons) {
    backlightFadeDown();
    cls(BLACK);
    image(29, 1, &mchp_meatball);
    image(15, 70, &microchip);
    backlightFadeTo(32);
    dState = DS_SCREENSAVER_HOLD;
}

void state_screensaver_hold(uint8_t buttons) {
    dState = DS_SCREENSAVER_EXIT;
}

void PIM_record(uint16_t address) {
    SPI1_Open();
    PIM_CS_LOW;
    SPI1_ExchangeByte(WRTEN);
    PIM_CS_HI;

    PIM_CS_LOW;
    SPI1_ExchangeByte(WRITE);
    SPI1_ExchangeByte(address >> 8);
    SPI1_ExchangeByte(address);

    SPI1_ExchangeByte(x); //capture[dTimer][0] = x;
    SPI1_ExchangeByte(y); //capture[dTimer][1] = y;
    SPI1_ExchangeByte(fineCount); //capture[dTimer][2] = fineCount;
    SPI1_ExchangeByte(courseCount); //capture[dTimer][3] = courseCount;
    SPI1_ExchangeByte(overflow); //mark the end of record
    PIM_CS_HI;

}
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

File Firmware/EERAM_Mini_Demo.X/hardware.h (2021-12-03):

 /**
  Hardware specific API Header File
	
  Company:
    Microchip Technology Inc.

  File Name:
    hardware.h

  Summary:
    Header file for initializing the hardware.

  Description:
     This header file provides APIs for initializing the hardware on PICDEM2 .net
     board.

 */

/*

©  [2015] Microchip Technology Inc. and its subsidiaries.  You may use this software 
and any derivatives exclusively with Microchip products. 
  
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
IN NO EVENT WILL MICROCHIP BE LIABLE FOR ANY INDIRECT, SPECIAL, PUNITIVE, INCIDENTAL 
OR CONSEQUENTIAL LOSS, DAMAGE, COST OR EXPENSE OF ANY KIND WHATSOEVER RELATED 
TO THE SOFTWARE, HOWEVER CAUSED, EVEN IF MICROCHIP HAS BEEN ADVISED OF THE POSSIBILITY 
OR THE DAMAGES ARE FORESEEABLE.  TO THE FULLEST EXTENT ALLOWED BY LAW, MICROCHIP'S 
TOTAL LIABILITY ON ALL CLAIMS IN ANY WAY RELATED TO THIS SOFTWARE WILL NOT EXCEED 
THE AMOUNT OF FEES, IF ANY, THAT YOU HAVE PAID DIRECTLY TO MICROCHIP FOR THIS SOFTWARE.

MICROCHIP PROVIDES THIS SOFTWARE CONDITIONALLY UPON YOUR ACCEPTANCE OF THESE TERMS. 

 */

#ifndef HARDWARE_H
#define	HARDWARE_H


#define SCL_LAT          LATBbits.LATB1
#define SCL_TRIS         TRISBbits.TRISB1    //-- The SCL Direction Register Bit
#define SCL_PORT         PORTBbits.RB1 

#define SDA_PORT         PORTBbits.RB2       //-- The SDA output pin
#define SDA_LAT          LATBbits.LATB2
#define SDA_TRIS         TRISBbits.TRISB2    //-- The SDA Direction Register Bit

//#define GEST_RESET_LAT   LATCbits.LATC0
//#define GEST_RESET_TRIS  TRISCbits.TRISC0

//#define GEST_EIO_TRIS    TRISCbits.TRISC2
//#define GEST_EIO_LAT     LATCbits.LATC2
//#define GEST_EIO_PORT    PORTCbits.RC2

#define LED_TRIS         TRISEbits.TRISE2
#define LED_ON()         do{LATEbits.LATE2=1;}while(0)
#define LED_OFF()        do{LATEbits.LATE2=0;}while(0)
#define LED_TOGGLE()     do{LATEbits.LATE2^=1;}while(0)

#define  BACKLIGHT_TRIS   TRISAbits.TRISA0
#define  BACKLIGHT_ON()   do{LATAbits.LATA0=1;}while(0)
#define  BACKLIGHT_OFF()  do{LATAbits.LATA0=0;}while(0)

// SPI Port I/O pins and CS interrupt registers
#define  SPI_MOSI_TRIS    TRISCbits.TRISC4       
#define  SPI_MISO_TRIS    TRISCbits.TRISC5
#define  SPI_SCK_TRIS     TRISBbits.TRISB0

#define  SPI_MOSI_LAT    LATCbits.LATC4       
#define  SPI_MISO_LAT    LATCbits.LATC5
#define  SPI_SCK_LAT     LATBbits.LATB0

//#define  SPI_MOSI_PPS()   do{SSP1DATPPS = 0b00010100;}while(0)  // RC4 = MOSI
//#define  SPI_MISO_PPS()   do{RC5PPS = 0x10;}while(0) //0b00010101;}while(0)  // RC5 = MISO
//#define  SPI_CLK_PPS()    do{SSP1CLKPPS = 0b00001000;}while(0)  // RB0 = SCK

#define  SPI_MOSI_PPS()   do{RC4PPS = 0x10;}while(0) //0b00010000;}while(0)  // RC4 = MOSI this works
#define  SPI_MISO_PPS()   do{SSP1DATPPS = 0x15;}while(0) //0b00010101;}while(0)  //  RC5 = MISO
#define  SPI_CLK_PPS()    do{RB0PPS = 0x0F;}while(0) //0b00001111;}while(0)  // RB0 = SCK

#define  CLIK_CS_TRIS      TRISCbits.TRISC6 // CS TRIS 
#define  CLIK_CS_PORT      PORTCbits.RC6    // CS PORT 
#define  CLIK_CS_LAT       LATCbits.LATC6
#define  CLIK_CS_LOW       do{LATCbits.LATC6 = 0;}while(0)
#define  CLIK_CS_HI        do{LATCbits.LATC6 = 1;}while(0)

#define  PIM_CS_TRIS      TRISAbits.TRISA7 // CS TRIS 
#define  PIM_CS_PORT      PORTAbits.RA7    // CS PORT 
#define  PIM_CS_LAT       LATAbits.LATA7
#define  PIM_CS_LOW       do{LATAbits.LATA7 = 0;}while(0)
#define  PIM_CS_HI        do{LATAbits.LATA7 = 1;}while(0)

// MOSI pin to SPI Memory devices plugged in
#define SPI_DATAOUT_PORT  PORTCbits.RC4
#define SPI_DATAOUT_TRIS  TRISCbits.TRISC4
#define SPI_DATAOUT_LAT   LATCbits.LATC4

// AUDIO Hardware selection
#define AUDIO_P_TRIS      TRISB4     // Speaker Positive output
#define AUDIO_N_TRIS      TRISB5     // Speaker Negative output
#define AUDIO_P_LAT       LATB4
#define AUDIO_N_LAT       LATB5

#define AUDIO_TMR         TMR3    // Use Timer 3 for Audio Tick (1KHz for tune, 8Khz for sound )
#define AUDIO_FREQ_TMR    TMR5    // Use timer 5 for Frequency Generator
#define AUDIO_PWM         PWM3    // Use PWM3 for sound generation

// DPad - Directional Control Pad (buttons) - Tony ****************************
#define UP_TRIS           TRISCbits.TRISC0
#define UP_LAT            LATCbits.LATC0
#define UP_PORT           PORTCbits.RC0

#define DOWN_TRIS         TRISCbits.TRISC1
#define DOWN_LAT          LATCbits.LATC1
#define DOWN_PORT         PORTCbits.RC1

#define LEFT_TRIS         TRISCbits.TRISC2
#define LEFT_LAT          LATCbits.LATC2
#define LEFT_PORT         PORTCbits.RC2

#define RIGHT_TRIS        TRISCbits.TRISC3
#define RIGHT_LAT         LATCbits.LATC3
#define RIGHT_PORT        PORTCbits.RC3

#define KEY_UP            0b00000100
#define KEY_DOWN          0b00000010
#define KEY_LEFT          0b00001000
#define KEY_RIGHT         0b00000001
#define ALL_KEY_MASK      0b00001111


// ****************************************************************************
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

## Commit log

2021-12-03 initial commit of collateral
    [EERAM Rally Mini Demo Bill of Materials.xls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]
2021-12-04 replaced source folder with firmware folder
    [audio.h, backlight.c]
